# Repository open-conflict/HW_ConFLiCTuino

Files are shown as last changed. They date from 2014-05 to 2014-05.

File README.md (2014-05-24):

HW_ConFLiCTuino
===============

<br>
<b>ConFLiCTuino 0.6: </b><br>
 <br>
 - changed PWM1 and PWM2 Header to the correct molex footprint. <br>
 - no electrical changes to 0.5 <br>
     <br>
 <br>
<b>ConFLiCTuino 0.5: </b><br>
 <br>
 - add 1-wire header  <br>
 - firmware compatible to 0.2, except of 1-Wire functionallity <br>
     <br>
 <br>
<b>ConFLiCTuino 0.4: </b><br>
 <br>
 - rework complete Layout for smaller size  <br>
 - changed resistor package to reduce part and assembly costs <br>
 - firmware compatible to 0.2 <br>
     <br>
 <br>
<b>ConFLiCTuino 0.3: </b><br>
 <br>
 - changed D1 and D3 to S1D type in DO214AC package  <br>
 - firmware compatible to 0.2 <br>
     <br>
 <br>
<b>ConFLiCTuino 0.2:  </b>   <br>
  <br>
 - changed pin mapping to arduino to use hardware functions     <br>
 - changed whole layout to match new pin mapping   <br>
 <br>
 <br>
<b>ConFLiCTuino 0.1:   </b> <br>
  <br>
 - first version     <br>

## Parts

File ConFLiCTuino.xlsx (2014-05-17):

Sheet: ConFliCTuino 0.5
Qty | SMD | Value | Device | Package | Parts | Reichelt Number | Additional Information
1 |  |  | 26Pin 2x13 Header | Vertical 2,54mm | EXT | WSL 26G
6 |  |  | 3Pin Fan Connector | Vertical 2,54mm | A1-OUT1, A1-OUT2, A2-OUT1, A2-OUT2, FM, 1WIRE | PSS 254/3G
2 |  |  | 4Pin Intel Fan Connector | Vertical 2,54mm | PWM1, PWM2 | not available | Molex: 47053-1000
1 |  |  | Arduino Mega2560 R3 |  | IC1 | ARDUINO MEGA | much cheaper boards via eBay, search for sainsmart mega
2 | x | BC847B | BC847B | SOT23 | Q2, Q3 | BC 847B SMD
7 | x | 100n | Ceramic Capacitor 16V 10% | 0805 | C1, C2, C3, C4, C7, C43, C51 | X7R-G0805 100N
2 | x | 22p | Ceramic Capacitor 16V 10% | 0805 | C49, C53 | NPO-G0805 22P
12 | x | 10µ | Ceramic Capacitor 16V 10% | 0805 | C5, C14, C15, C16, C17, C18, C19, C20, C21, C28, C48, C52 | X5R-G0805 10/16
3 | x | 1µ | Ceramic Capacitor 16V 10% | 0805 | C6, C50, C54 | X5R-G0805 1,0/16
1 | x | 22n | Ceramic Capacitor 16V 10% | 0805 | C25 | X7R-G0805 22N
1 |  | Power | FLOP-4 | 350211 | PWR | PSG 5
2 | x | IRF9Z34NS | IRF9Z34NS | D2PACK | Q7, Q8 | IRF 9Z34NS
3 | x | IRLR024N | IRLR024N | DPACK | Q1, Q5, Q6 | IRLR 024N
1 | x | LM358D | LM358 | SO08 | IC4 | LM 358 SMD
1 | x | 10k NTC 3730K | NTC sensor | 0805 | R9 | not available
1 |  |  | Pinhead 1x3 | Vertical 2,54mm | JP3 | SL 1X50G 2,54 | only 1 part needed, cut it!
1 |  |  | Pinhead 1x7 | Vertical 2,54mm | IC1
4 |  |  | Pinhead 1x8 | Vertical 2,54mm | IC1
1 |  |  | Pinhead 2x18 | Vertical 2,54mm | IC1 | SL 2X40G 2,54 | only 1 part needed, cut it!
1 |  |  | Pinhead 2x4 | Vertical 2,54mm | LED
1 |  |  | Pinhead 2x7 | Vertical 2,54mm | TEMP
0 | x | 0 | Resistor 1% 0.125W | 0805 | R10 | SMD-0805 0,00 | assemble only for old revisions (< R3) of arduino mega boards
2 | x | 1K | Resistor 1% 0.125W | 0805 | R14, R15 | SMD-0805 1,00K
2 | x | 33k | Resistor 1% 0.125W | 0805 | R16, R23 | SMD-0805 33,0K
2 | x | 3k3 | Resistor 1% 0.125W | 0805 | R25, R27 | SMD-0805 3,30K
4 | x | 47k | Resistor 1% 0.125W | 0805 | R12, R13, R24, R26 | SMD-0805 47,0K
2 | x | 4k7 | Resistor 1% 0.125W | 0805 | R1, R31 | SMD-0805 4,70K
1 |  | 27K | Resistornet star 8x27K/9Pin | RN-9 | RN1 | SIL 9-8 27K
1 | x | 4k7 | 4x Resitornet parallel | 1206 | RN3 | BCN16 4,7K
1 | x | 10k | 4x Resitornet parallel | 1206 | RN2 | BCN16 10K
1 | x | 220 | 4x Resitornet parallel | 1206 | RN5 | BCN16 220
2 | x | S1D | SI-Diode | DO214AC | D1, D3 | S 1D SMD
1 |  | 8,5 K/W | Heatsink | 51x18.9x4.8mm |  | V 5619E | assemble with thermal grease and pads

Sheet: ConFliCTuino 0.4
Qty | SMD | Value | Device | Package | Parts | Reichelt Number | Additional Information
1 |  |  | 26Pin 2x13 Header | Vertical 2,54mm | EXT | WSL 26G
5 |  |  | 3Pin Fan Connector | Vertical 2,54mm | A1-OUT1, A1-OUT2, A2-OUT1, A2-OUT2, FM | PSS 254/3G
2 |  |  | 4Pin Intel Fan Connector | Vertical 2,54mm | PWM1, PWM2 | not available | Molex: 47053-1000
1 |  |  | Arduino Mega2560 R3 |  | IC1 | ARDUINO MEGA | much cheaper boards via eBay, search for sainsmart mega
2 | x | BC847B | BC847B | SOT23 | Q2, Q3 | BC 847B SMD
6 | x | 100n | Ceramic Capacitor 16V 10% | 0805 | C1, C2, C3, C4, C43, C51 | X7R-G0805 100N
2 | x | 10p | Ceramic Capacitor 16V 10% | 0805 | C49, C53 | NPO-G0805 10P
12 | x | 10µ | Ceramic Capacitor 16V 10% | 0805 | C5, C14, C15, C16, C17, C18, C19, C20, C21, C28, C48, C52 | X5R-G0805 10/16
3 | x | 1µ | Ceramic Capacitor 16V 10% | 0805 | C6, C50, C54 | X5R-G0805 1,0/16
1 | x | 22n | Ceramic Capacitor 16V 10% | 0805 | C25 | X7R-G0805 22N
1 |  | Power | FLOP-4 | 350211 | PWR | PSG 5
2 | x | IRF9Z34NS | IRF9Z34NS | D2PACK | Q7, Q8 | IRF 9Z34NS
3 | x | IRLR024N | IRLR024N | DPACK | Q1, Q5, Q6 | IRLR 024N
1 | x | LM358D | LM358 | SO08 | IC4 | LM 358 SMD
1 | x | 10k NTC 3730K | NTC sensor | 0805 | R9 | not available
1 |  |  | Pinhead 1x3 | Vertical 2,54mm | JP3 | SL 1X50G 2,54 | only 1 part needed, cut it!
1 |  |  | Pinhead 1x7 | Vertical 2,54mm | IC1
4 |  |  | Pinhead 1x8 | Vertical 2,54mm | IC1
1 |  |  | Pinhead 2x18 | Vertical 2,54mm | IC1 | SL 2X40G 2,54 | only 1 part needed, cut it!
1 |  |  | Pinhead 2x4 | Vertical 2,54mm | LED
1 |  |  | Pinhead 2x7 | Vertical 2,54mm | TEMP
0 | x | 0 | Resistor 1% 0.125W | 0805 | R10 | SMD-0805 0,00 | assemble only for old revisions (< R3) of arduino mega boards
2 | x | 1K | Resistor 1% 0.125W | 0805 | R14, R15 | SMD-0805 1,00K
2 | x | 33k | Resistor 1% 0.125W | 0805 | R16, R23 | SMD-0805 33,0K
2 | x | 3k3 | Resistor 1% 0.125W | 0805 | R25, R27 | SMD-0805 3,30K
4 | x | 47k | Resistor 1% 0.125W | 0805 | R12, R13, R24, R26 | SMD-0805 47,0K
1 | x | 4k7 | Resistor 1% 0.125W | 0805 | R31 | SMD-0805 4,70K
1 |  | 27K | Resistornet star 8x27K/9Pin | RN-9 | RN1 | SIL 9-8 27K
1 | x | 4k7 | 4x Resitornet parallel | 1206 | RN3 | BCN16 4,7K
1 | x | 10k | 4x Resitornet parallel | 1206 | RN2 | BCN16 10K
1 | x | 220 | 4x Resitornet parallel | 1206 | RN5 | BCN16 220
2 | x | S1D | SI-Diode | DO214AC | D1, D3 | S 1D SMD
1 |  | 8,5 K/W | Heatsink | 51x18.9x4.8mm |  | V 5619E | assemble with thermal grease and pads

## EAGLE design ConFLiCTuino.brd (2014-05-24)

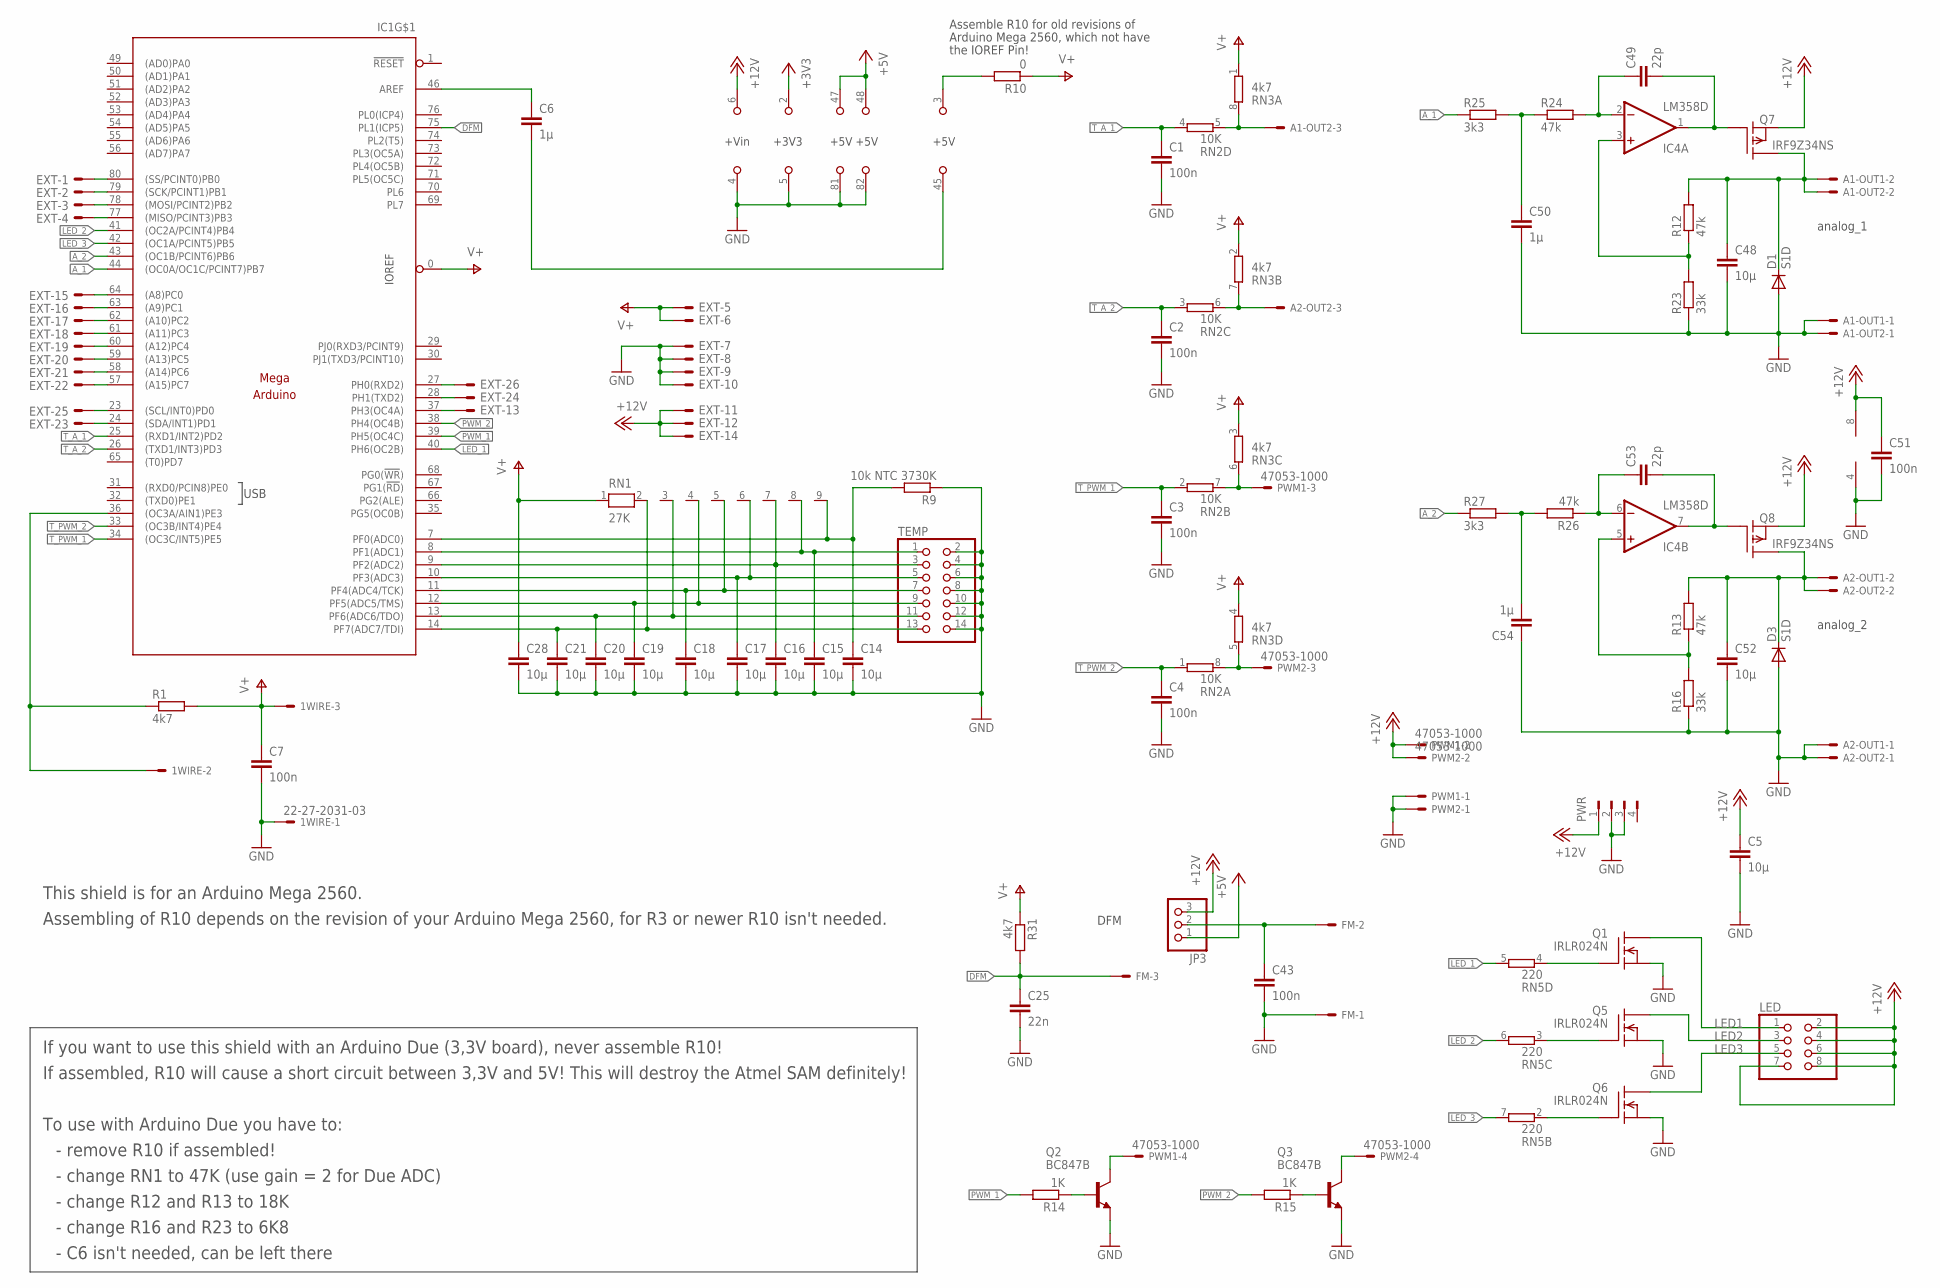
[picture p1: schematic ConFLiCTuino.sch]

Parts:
1WIRE: 22-27-2031-03; 6410-03
A1-OUT1, A1-OUT2, A2-OUT1, A2-OUT2: 22-27-2031-03; 6410-03
C1, C2, C3, C4, C7, C43, C51: 100n; C0805K
C5, C14, C15, C16, C17, C18, C19, C20, C21, C28, C48, C52: 10µ; C0805K
C6, C50, C54: 1µ; C0805K
C25: 22n; C0805K
C49, C53: 22p; C0805K
D1, D3: S1D; DO214AC
EXT: ML26E; ML26
FM: 22-27-2031-03; 6410-03
IC1: MEGAARDUINO_CUSTOM; ARDUINO_MEGA_R3_SMALL_CUSTOM
IC4: LM358D; SO08
JP3: PINHD-1X3; 1X03
LED: PINHD-2X4; 2X04
PWM1, PWM2: 47053-1000
PWR: FLOPPY-4350211; 350211
Q1, Q5, Q6: IRLR024N; DPACK
Q2, Q3: BC847B; SOT23
Q7, Q8: IRF9Z34NS; D2PACK
R1, R31: 4k7; M0805
R9: 10k NTC 3730K; M0805
R10: 0; M0805
R12, R13, R24, R26: 47k; M0805
R14, R15: 1K; M0805
R16, R23: 33k; M0805
R25, R27: 3k3; M0805
RN1: 27K; RN-9
RN2: 10K; CAT16
RN3: 4k7; CAT16
RN5: 220; CAT16
TEMP: PINHD-2X7; 2X07

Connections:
+3V3: IC1.2 (+3V3)
+5V: IC1.47 (+5V), IC1.48 (+5V), JP3.1
+12V: C5.1, C51.1, EXT.11, EXT.12, EXT.14, IC1.6 (+VIN), IC4.8 (V+), JP3.3, LED.2, LED.4, LED.6, LED.7, LED.8, PWM1.2, PWM2.2, PWR.1, Q7.3 (S), Q8.3 (S)
A_1: IC1.44 ((OC0A/OC1C/PCINT7)PB7), R25.1
A_2: IC1.43 ((OC1B/PCINT6)PB6), R27.1
DFM: C25.1, FM.3, IC1.75 (PL1(ICP5)), R31.2
GND: 1WIRE.1, A1-OUT1.1, A1-OUT2.1, A2-OUT1.1, A2-OUT2.1, C1.2, C2.2, C3.2, C4.2, C5.2, C7.2, C14.2, C15.2, C16.2, C17.2, C18.2, C19.2, C20.2, C21.2, C25.2, C28.2, C43.2, C48.2, C50.2, C51.2, C52.2, C54.1, D1.A, D3.A, EXT.7, EXT.8, EXT.9, EXT.10, FM.1, IC1.4 (GND), IC1.5 (GND), IC1.81 (GND), IC1.82 (GND), IC4.4 (V-), PWM1.1, PWM2.1, PWR.2, PWR.3, Q1.3 (S), Q2.2 (E), Q3.2 (E), Q5.3 (S), Q6.3 (S), R9.1, R16.1, R23.1, TEMP.2, TEMP.4, TEMP.6, TEMP.8, TEMP.10, TEMP.12, TEMP.14
LED1: LED.1, Q1.4 (D)
LED2: LED.3, Q5.4 (D)
LED3: LED.5, Q6.4 (D)
LED_1: IC1.40 (PH6(OC2B)), RN5.5 (2)
LED_2: IC1.41 ((OC2A/PCINT4)PB4), RN5.6 (2)
LED_3: IC1.42 ((OC1A/PCINT5)PB5), RN5.7 (2)
unnamed: EXT.23, IC1.24 ((SDA/INT1)PD1)
unnamed: A1-OUT2.3, RN2.5 (2), RN3.8 (2)
unnamed: A2-OUT1.2, A2-OUT2.2, C52.1, D3.C, Q8.2 (D), R13.2
unnamed: EXT.24, IC1.28 (PH1(TXD2))
unnamed: A2-OUT2.3, RN2.6 (2), RN3.7 (2)
unnamed: IC4.3 (+IN), R12.1, R23.2
unnamed: EXT.25, IC1.23 ((SCL/INT0)PD0)
unnamed: C49.2, IC4.1 (OUT), Q7.1 (G)
unnamed: EXT.26, IC1.27 (PH0(RXD2))
unnamed: EXT.22, IC1.57 ((A15)PC7)
unnamed: C43.1, FM.2, JP3.2
unnamed: PWM1.3, RN2.7 (2), RN3.6 (2)
unnamed: EXT.21, IC1.58 ((A14)PC6)
unnamed: PWM2.3, RN2.8 (2), RN3.5 (2)
unnamed: EXT.20, IC1.59 ((A13)PC5)
unnamed: IC4.5 (+IN), R13.1, R16.2
unnamed: EXT.19, IC1.60 ((A12)PC4)
unnamed: C49.1, IC4.2 (-IN), R24.2
unnamed: Q2.1 (B), R14.1
unnamed: A1-OUT1.2, A1-OUT2.2, C48.1, D1.C, Q7.2 (D), R12.2
unnamed: Q3.1 (B), R15.1
unnamed: PWM1.4, Q2.3 (C)
unnamed: EXT.18, IC1.61 ((A11)PC3)
unnamed: C53.2, IC4.7 (OUT), Q8.1 (G)
unnamed: PWM2.4, Q3.3 (C)
unnamed: EXT.17, IC1.62 ((A10)PC2)
unnamed: EXT.16, IC1.63 ((A9)PC1)
unnamed: EXT.15, IC1.64 ((A8)PC0)
unnamed: EXT.2, IC1.79 ((SCK/PCINT1)PB1)
unnamed: EXT.1, IC1.80 ((SS/PCINT0)PB0)
unnamed: EXT.4, IC1.77 ((MISO/PCINT3)PB3)
unnamed: EXT.3, IC1.78 ((MOSI/PCINT2)PB2)
unnamed: C14.1, IC1.7 (PF0(ADC0)), R9.2, RN1.9
unnamed: C15.1, IC1.8 (PF1(ADC1)), RN1.8, TEMP.1
unnamed: C16.1, IC1.9 (PF2(ADC2)), RN1.7, TEMP.3
unnamed: C17.1, IC1.10 (PF3(ADC3)), RN1.6, TEMP.5
unnamed: C18.1, IC1.11 (PF4(ADC4/TCK)), RN1.5, TEMP.7
unnamed: C19.1, IC1.12 (PF5(ADC5/TMS)), RN1.4, TEMP.9
unnamed: C20.1, IC1.13 (PF6(ADC6/TDO)), RN1.3, TEMP.11
unnamed: C21.1, IC1.14 (PF7(ADC7/TDI)), RN1.2, TEMP.13
unnamed: EXT.13, IC1.37 (PH3(OC4A))
unnamed: C6.1, IC1.46 (AREF)
unnamed: C6.2, IC1.45 (GND)
unnamed: 1WIRE.2, IC1.36 ((OC3A/AIN1)PE3), R1.1
unnamed: C50.1, R24.1, R25.2
unnamed: C53.1, IC4.6 (-IN), R26.1
unnamed: C54.2, R26.2, R27.2
unnamed: Q6.1 (G), RN5.2 (1)
unnamed: Q5.1 (G), RN5.3 (1)
unnamed: Q1.1 (G), RN5.4 (1)
PWM_1: IC1.39 (PH5(OC4C)), R14.2
PWM_2: IC1.38 (PH4(OC4B)), R15.2
S$2: IC1.3 (+5V), R10.2
T_A_1: C1.1, IC1.25 ((RXD1/INT2)PD2), RN2.4 (1)
T_A_2: C2.1, IC1.26 ((TXD1/INT3)PD3), RN2.3 (1)
T_PWM_1: C3.1, IC1.34 ((OC3C/INT5)PE5), RN2.2 (1)
T_PWM_2: C4.1, IC1.33 ((OC3B/INT4)PE4), RN2.1
V+: 1WIRE.3, C7.1, C28.1, EXT.5, EXT.6, IC1.0 (IOREF), R1.2, R10.1, R31.1, RN1.1, RN3.1, RN3.2 (1), RN3.3 (1), RN3.4 (1)

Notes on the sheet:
analog_2
analog_1
DFM
Assemble R10 for old revisions of
Arduino Mega 2560, which not have
the IOREF Pin!
This shield is for an Arduino Mega 2560.
Assembling of R10 depends on the revision of your Arduino Mega 2560, for R3 or newer R10 isn't needed.
If you want to use this shield with an Arduino Due (3,3V board), never assemble R10!
If assembled, R10 will cause a short circuit between 3,3V and 5V! This will destroy the Atmel SAM definitely!
To use with Arduino Due you have to:
- change RN1 to 47K (use gain = 2 for Due ADC)
- change R12 and R13 to 18K
- change R16 and R23 to 6K8
- C6 isn't needed, can be left there
- remove R10 if assembled!
USB

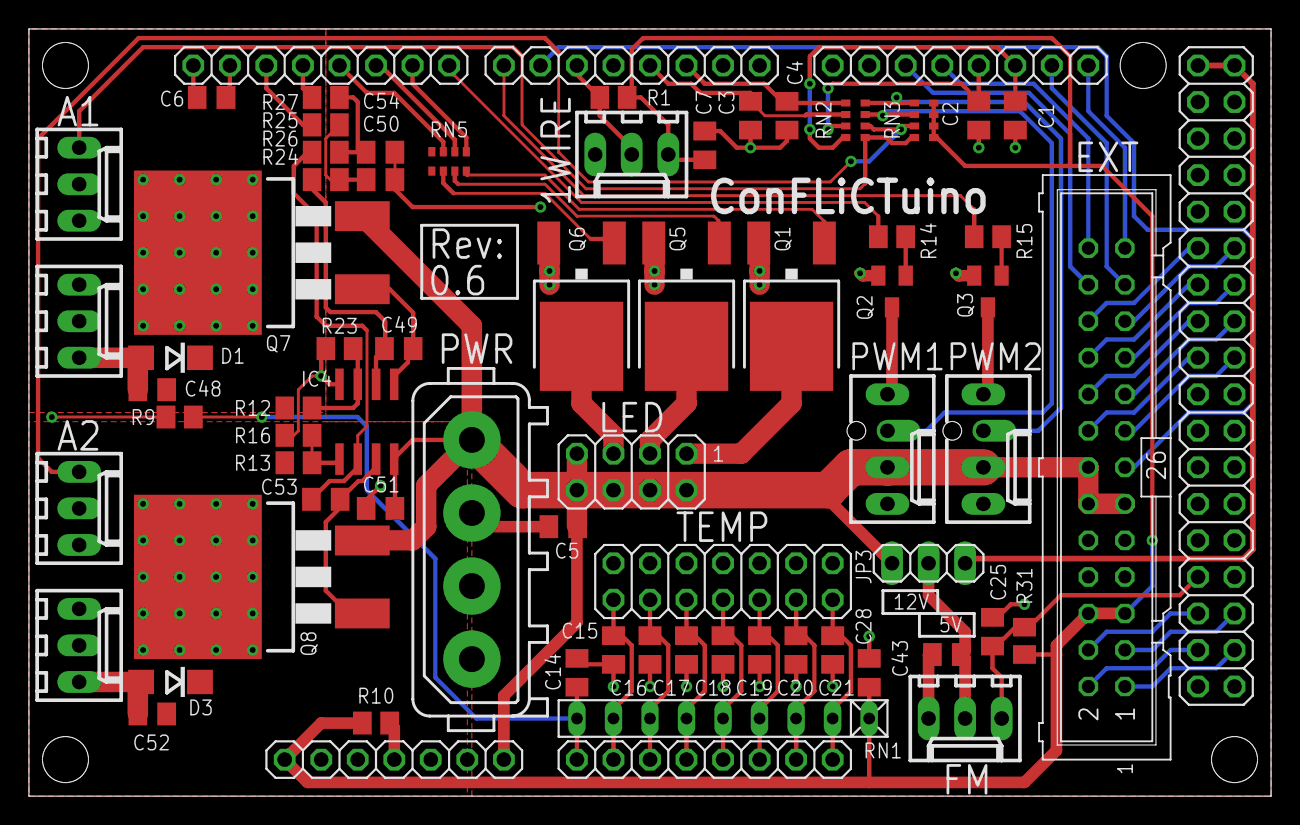
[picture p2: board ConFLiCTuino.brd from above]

Board: 2 copper layers, 86.4 x 53.3 mm, 67 parts (0 on the bottom side), 70 nets.

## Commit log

2014-04-09 Init V0.2
    [ConFLiCTuino.brd, ConFLiCTuino.sch, ConFLiCTuino.xlsx]
2014-04-09 init V0.3
    [ConFLiCTuino.brd, ConFLiCTuino.sch, ConFLiCTuino.xlsx]
2014-04-23 Init V0.4
    Changed whole layout. More resistor nets and smaller board.
    [ConFLiCTuino.brd, ConFLiCTuino.sch, ConFLiCTuino.xlsx]
2014-05-01 init V0.5
    Added 1-Wire header
2014-05-04 Schaltplan schick gemacht
    [ConFLiCTuino.sch]
2014-05-11 warnings in ERC checked
    only uneccessarry things
    [ConFLiCTuino.sch]
2014-05-17 partlist updated to V0.5
    Added new tab in excel with the partlist for the V0.5 board
    [ConFLiCTuino.xlsx]
2014-05-24 init V0.6
    Changed 4-Pol PWM connectors to Molex-Footprint with hole for the kex
    pin.
    [ConFLiCTuino.brd, ConFLiCTuino.sch]
